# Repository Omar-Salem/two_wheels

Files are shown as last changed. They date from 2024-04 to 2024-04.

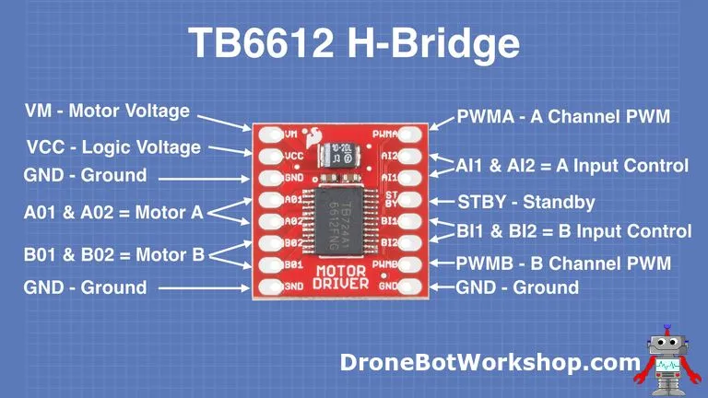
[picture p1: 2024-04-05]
two_wheels_core/firmware/docs/TB6612FNG-pinout.png

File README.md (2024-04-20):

### Validate URDF file

``` bash 
check_urdf two_wheels_core/urdf/robot_core.xacro
```

## Build and run simulation

```bash
cd ros2_ws/
rm -rf build/ install/ log/
colcon build && source install/setup.bash && ros2 launch two_wheels_core sim_two_wheels.launch.py
````

## Build and run real

[//]: # (### Log into on Pi)

[//]: # (```bash)

[//]: # (ssh omar.salem@192.168.1.35)

[//]: # (```)

### Prepare docker on Pi (_first time/on code change_)
```bash
HOST=omar.salem@192.168.1.35
scp prepare_docker.sh $HOST:/tmp/ && ssh -t $HOST "sudo -s bash /tmp/prepare_docker.sh"
```

### Run microros

```bash
ssh omar.salem@192.168.1.35
docker run --rm --privileged -it -v ~/Volumes:/home/usr/ humble
#contents of run_microros.sh
```

### Run robot

```bash
ssh omar.salem@192.168.1.35
docker exec -it $(docker container ls  | grep 'humble' | awk '{print $1}') bash
#contents of run_robot.sh
```

### Test
```bash
ssh omar.salem@192.168.1.35
docker exec -it $(docker container ls  | grep 'humble' | awk '{print $1}') bash
ros2 topic pub -r 10 /diff_drive_controller/cmd_vel_unstamped geometry_msgs/msg/Twist "
  linear:
    x: 0.5"

````

### Debug

- Is Esp32 LED on?
- Do Motors Have power ?
```bash

ls /dev/tty* | grep USB #sanity check to see if usb devices are reachable
ros2 topic list | grep motors #sanity check to see if /two_wheels/motors_* topics exist

source ~/microros_ws/install/local_setup.bash
ros2 topic echo /two_wheels/motors_state #sanity check to see if topics emit

ros2 topic pub -r 10 /two_wheels/motors_cmd two_wheels_interfaces/msg/MotorsOdom "m1:
  velocity: 1.5
m2:
  velocity: 1.50"
````

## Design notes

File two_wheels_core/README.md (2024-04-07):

### Validate URDF file

```check_urdf /PATH/TO/URDF```

### Build and run simulation

```bash
cd ros2_ws/
rm -rf build/ install/ log/
colcon build && source install/setup.bash && ros2 launch two_wheels_core sim_two_wheels.launch.py
````

### Log into on Pi
```bash
ssh omar.salem@192.168.1.35
```

### Prepare docker on Pi (first time/on repo change)
```bash
sudo rm -rf ~/Volumes
mkdir -p ~/Volumes/ros2_ws/src
cd ~/Volumes
mkdir microros_ws
cd $_
git clone -b humble https://github.com/micro-ROS/micro_ros_setup.git src/micro_ros_setup
cd ~/Volumes/ros2_ws/src
git clone https://github.com/Omar-Salem/two_wheels.git
git clone https://github.com/Slamtec/sllidar_ros2.git
pip install -U colcon-common-extensions
source sllidar_ros2/scripts/create_udev_rules.sh
mv two_wheels/* ~/Volumes/ros2_ws/src/
#mv two_wheels/Dockerfile ~/Volumes/ros2_ws/src/  # TODO needed?
rm -rf two_wheels
docker system prune --volumes --all -f
docker build -t humble .
```

### Build and run real

```bash
ls /dev/tty* | grep USB #sanity check to see if usb devices are reachable
docker run --rm --privileged -it -v ~/Volumes:/home/usr/ humble

ros2 topic list | grep motors #sanity check to see if topics exist

ros2 topic pub -r 10 /diff_drive_controller/cmd_vel_unstamped geometry_msgs/msg/Twist "
  linear:
    x: 1.0
    y: 0.0
    z: 0.0
  angular:
    x: 0.0
    y: 0.0
    z: 0.0"
````

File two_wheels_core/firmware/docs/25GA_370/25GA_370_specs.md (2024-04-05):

https://mikroelectron.com/Product/25GA-370-12V-400RPM-DC-Reducer-Gear-Motor-with-Encoder

| Power Source | Board | ESP32 | Motors | TB6612FNG |
|---|---|---|---|---|
| + | | | | VM |
| GND | GND | GND | M1 Black  - negative of encoder power supply(-)(3.3-5V) | GND |
| | + | 5V | M1 BLue - positive of encoder power supply(+)(3.3-5V) | STBY,VCC |
| | | | M1 Red  - positive power supply (+) | A0 |
| | | | M1 White  - negative power supply (-) | A1 |
| | | 16 | | PWMA |
| | | 4 | | AI1 |
| | | 0 | | AI2 |
| | | 23 | M1 Yellow | |
| | | 22 | M1 Green | |
| -------------- | ------- | ------- | --------------------------------------------------------- | ----------- |
| | GND | | M2 Black  - negative of encoder power supply(-)(3.3-5V) | |
| | + | | M2 BLue - positive of encoder power supply(+)(3.3-5V) | |
| | | | M2 White  - negative power supply  (-) | B0 |
| | | | M2 Red  - positive power supply (+) | B1 |
| | | 27 | | PWMB |
| | | 12 | | BI1 |
| | | 14 | | BI2 |
| | | 36 | M2 Yellow  - M2 | |
| | | 39 | M2 Green  - M2 | |

https://www.openimpulse.com/blog/products-page/25d-gearmotors/jga25-370-dc-gearmotor-77-rpm-6-v/

Specifications
Operating voltage: between 3 V and 9 V
Nominal voltage: 6 V
Free-run speed at 6 V: 77 RPM
Free-run current at 6 V: 80 mA
Stall current at 6V: 900 mA
Stall torque at 6V: 10 kg·cm
Gear ratio: 1:78
Reductor size: 23 mm
Weight: 88 g

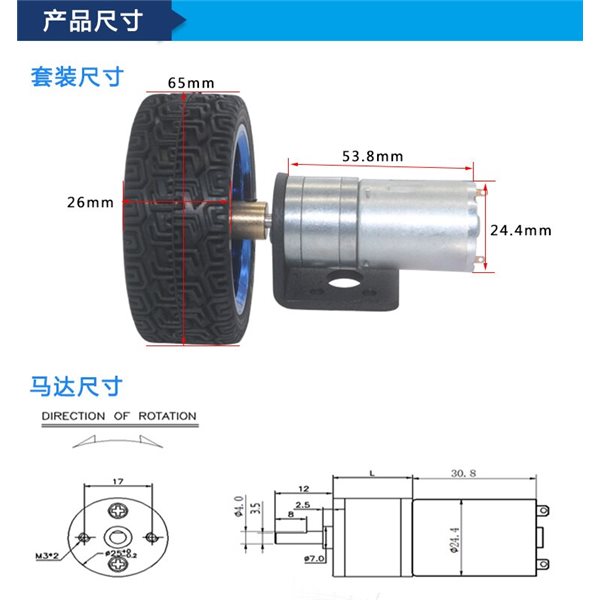
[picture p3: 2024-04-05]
two_wheels_core/firmware/docs/25GA_370/dimensions.jpg

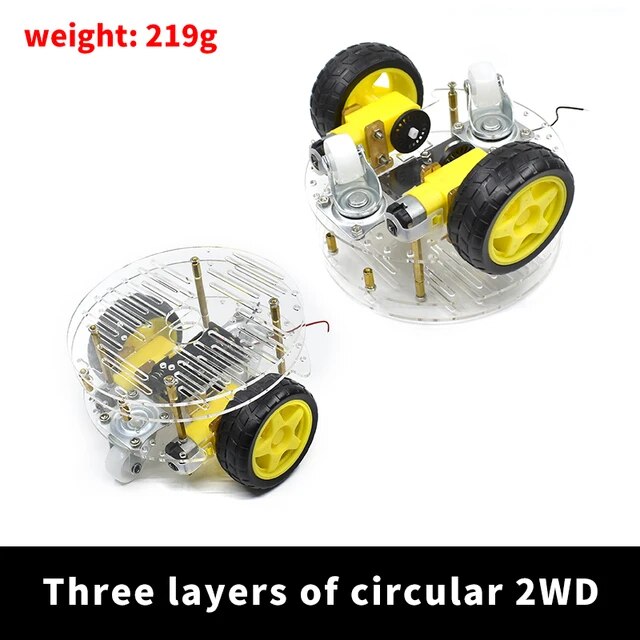
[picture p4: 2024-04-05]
two_wheels_core/firmware/docs/robot.png

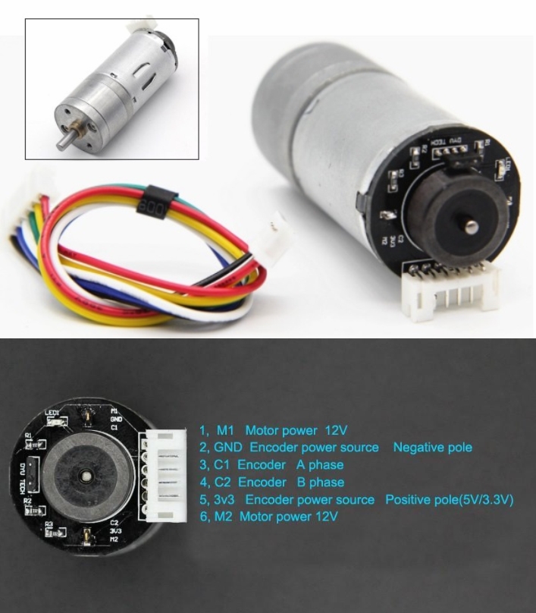
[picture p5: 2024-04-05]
two_wheels_core/firmware/docs/25GA_370/25GA-370 6V 620RPM DC REDUCER GEAR MOTOR WITH ENCODER.jpg

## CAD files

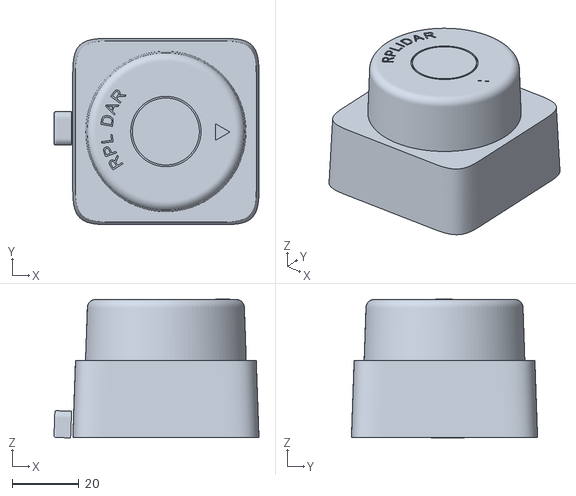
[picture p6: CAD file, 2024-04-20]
two_wheels_core/urdf/meshes/lidar_link.stl
61.2 x 55.6 x 41.5

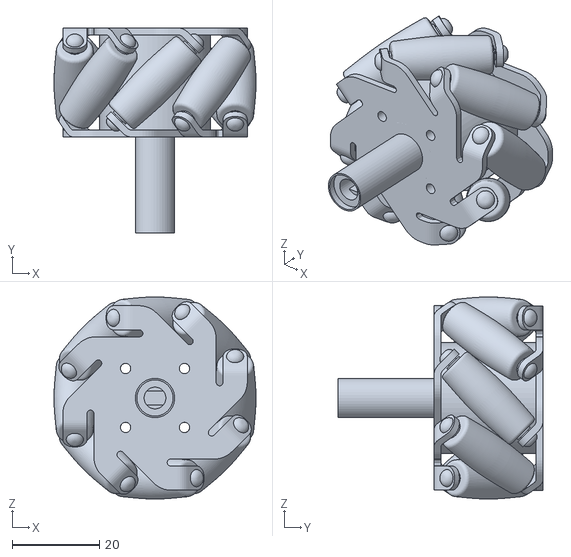
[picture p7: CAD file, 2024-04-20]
two_wheels_core/urdf/meshes/front_left_wheel.stl
46.3 x 47.0 x 46.3

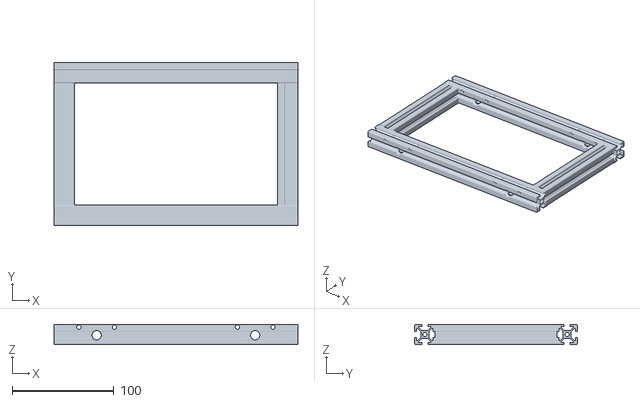
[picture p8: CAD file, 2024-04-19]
two_wheels_core/urdf/meshes/base_link.stl
240.0 x 160.0 x 20.0

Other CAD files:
two_wheels_core/urdf/meshes/rear_right_wheel.stl
two_wheels_core/urdf/meshes/front_right_wheel.stl
two_wheels_core/urdf/meshes/rear_left_wheel.stl

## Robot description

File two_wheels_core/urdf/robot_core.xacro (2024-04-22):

<?xml version="1.0"?>
<robot xmlns:xacro="http://www.ros.org/wiki/xacro">
    <xacro:include filename="$(find two_wheels_core)/urdf/materials.xacro"/>
    <link name="base_link">
        <inertial>
            <origin xyz="7.136447167432144e-05 3.453515765351803e-05 0.024408245184796683" rpy="0 0 0"/>
            <mass value="1.000593039456424"/>
            <inertia ixx="0.003708" iyy="0.007317" izz="0.010943" ixy="-0.0" iyz="-0.0" ixz="-0.0"/>
        </inertial>
        <visual>
            <origin xyz="0 0 0" rpy="0 0 0"/>
            <geometry>
                <mesh filename="file://$(find two_wheels_core)/urdf/meshes/base_link.stl" scale="0.001 0.001 0.001"/>
            </geometry>
            <material name="silver"/>
        </visual>
        <collision>
            <origin xyz="0 0 0" rpy="0 0 0"/>
            <geometry>
                <mesh filename="file://$(find two_wheels_core)/urdf/meshes/base_link.stl" scale="0.001 0.001 0.001"/>
            </geometry>
        </collision>
    </link>

    <link name="rear_right_wheel">
        <inertial>
            <origin xyz="1.625960121487413e-06 -0.03356595189466297 -1.9609319341917786e-09" rpy="0 0 0"/>
            <mass value="0.21820489062799583"/>
            <inertia ixx="3.8e-05" iyy="4.8e-05" izz="3.8e-05" ixy="0.0" iyz="0.0" ixz="0.0"/>
        </inertial>
        <visual>
            <origin xyz="0.077933 0.059968 -0.023743" rpy="0 0 0"/>
            <geometry>
                <mesh filename="file://$(find two_wheels_core)/urdf/meshes/rear_right_wheel.stl" scale="0.001 0.001 0.001"/>
            </geometry>
            <material name="black"/>
        </visual>
        <collision>
            <origin xyz="0.077933 0.059968 -0.023743" rpy="0 0 0"/>
            <geometry>
                <mesh filename="file://$(find two_wheels_core)/urdf/meshes/rear_right_wheel.stl" scale="0.001 0.001 0.001"/>
            </geometry>
        </collision>
    </link>

    <link name="front_right_wheel">
        <inertial>
            <origin xyz="1.3407781088436987e-06 -0.03356595189466117 -1.9609318023527944e-09" rpy="0 0 0"/>
            <mass value="0.2182048906279955"/>
            <inertia ixx="3.8e-05" iyy="4.8e-05" izz="3.8e-05" ixy="0.0" iyz="0.0" ixz="0.0"/>
        </inertial>
        <visual>
            <origin xyz="-0.077933 0.059968 -0.023743" rpy="0 0 0"/>
            <geometry>
                <mesh filename="file://$(find two_wheels_core)/urdf/meshes/front_right_wheel.stl" scale="0.001 0.001 0.001"/>
            </geometry>
            <material name="black"/>
        </visual>
        <collision>
            <origin xyz="-0.077933 0.059968 -0.023743" rpy="0 0 0"/>
            <geometry>
                <mesh filename="file://$(find two_wheels_core)/urdf/meshes/front_right_wheel.stl" scale="0.001 0.001 0.001"/>
            </geometry>
        </collision>
    </link>

    <link name="front_left_wheel">
        <inertial>
            <origin xyz="1.4899030495729715e-06 0.03356602362407317 3.1974513525767634e-07" rpy="0 0 0"/>
            <mass value="0.2182048906279955"/>
            <inertia ixx="3.8e-05" iyy="4.8e-05" izz="3.8e-05" ixy="-0.0" iyz="0.0" ixz="-0.0"/>
        </inertial>
        <visual>
            <origin xyz="-0.077931 -0.060032 -0.023742" rpy="0 0 0"/>
            <geometry>
                <mesh filename="file://$(find two_wheels_core)/urdf/meshes/front_left_wheel.stl" scale="0.001 0.001 0.001"/>
            </geometry>
            <material name="black"/>
        </visual>
        <collision>
            <origin xyz="-0.077931 -0.060032 -0.023742" rpy="0 0 0"/>
            <geometry>
                <mesh filename="file://$(find two_wheels_core)/urdf/meshes/front_left_wheel.stl" scale="0.001 0.001 0.001"/>
            </geometry>
        </collision>
    </link>

    <link name="rear_left_wheel">
        <inertial>
            <origin xyz="-1.489903047255381e-06 0.033566023624073626 8.554326641832533e-08" rpy="0 0 0"/>
            <mass value="0.2182048906279955"/>
            <inertia ixx="3.8e-05" iyy="4.8e-05" izz="3.8e-05" ixy="0.0" iyz="-0.0" ixz="-0.0"/>
        </inertial>
        <visual>
            <origin xyz="0.077931 -0.060032 -0.023742" rpy="0 0 0"/>
            <geometry>
                <mesh filename="file://$(find two_wheels_core)/urdf/meshes/rear_left_wheel.stl" scale="0.001 0.001 0.001"/>
            </geometry>
            <material name="black"/>
        </visual>
        <collision>
            <origin xyz="0.077931 -0.060032 -0.023742" rpy="0 0 0"/>
            <geometry>
                <mesh filename="file://$(find two_wheels_core)/urdf/meshes/rear_left_wheel.stl" scale="0.001 0.001 0.001"/>
            </geometry>
        </collision>
    </link>

    <joint name="rear_right_wheel_joint" type="continuous">
        <origin xyz="-0.077933 -0.059968 0.023743" rpy="0 0 0"/>
        <parent link="base_link"/>
        <child link="rear_right_wheel"/>
        <axis xyz="0.0 1.0 0.0"/>
    </joint>

    <joint name="front_right_wheel_joint" type="continuous">
        <origin xyz="0.077933 -0.059968 0.023743" rpy="0 0 0"/>
        <parent link="base_link"/>
        <child link="front_right_wheel"/>
        <axis xyz="0.0 1.0 0.0"/>
    </joint>

    <joint name="front_left_wheel_joint" type="continuous">
        <origin xyz="0.077931 0.060032 0.023742" rpy="0 0 0"/>
        <parent link="base_link"/>
        <child link="front_left_wheel"/>
        <axis xyz="0.0 1.0 0.0"/>
    </joint>

    <joint name="rear_left_wheel_joint" type="continuous">
        <origin xyz="-0.077931 0.060032 0.023742" rpy="0 0 0"/>
        <parent link="base_link"/>
        <child link="rear_left_wheel"/>
        <axis xyz="0.0 1.0 0.0"/>
    </joint>

    <link name="lidar_link">
        <inertial>
            <origin xyz="-0.00011530732368342234 3.558559248059221e-06 0.017945212221916012" rpy="0 0 0"/>
            <mass value="0.7886321015037847"/>
            <inertia ixx="0.000269" iyy="0.000272" izz="0.000333" ixy="0.0" iyz="0.0" ixz="-1e-06"/>
        </inertial>
        <visual>
            <origin xyz="-0.11007 -3.2e-05 -0.028463" rpy="0 0 0"/>
            <geometry>
                <mesh filename="file://$(find two_wheels_core)/urdf/meshes/lidar_link.stl" scale="0.001 0.001 0.001"/>
            </geometry>
            <material name="black"/>
        </visual>
        <collision>
            <origin xyz="-0.11007 -3.2e-05 -0.028463" rpy="0 0 0"/>
            <geometry>
                <mesh filename="file://$(find two_wheels_core)/urdf/meshes/lidar_link.stl" scale="0.001 0.001 0.001"/>
            </geometry>
        </collision>
    </link>

    <joint name="lidar_link_joint" type="fixed">
        <origin xyz="0.11007 3.2e-05 0.028463" rpy="0 0 0"/>
        <parent link="base_link"/>
        <child link="lidar_link"/>
    </joint>

    <link name="base_footprint"/>

    <joint name="base_footprint_joint" type="fixed">
        <parent link="base_link"/>
        <child link="base_footprint"/>
        <origin xyz="0 0 0" rpy="0 0 0"/>
    </joint>

</robot>

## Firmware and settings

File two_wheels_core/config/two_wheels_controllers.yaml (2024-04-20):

controller_manager:
  ros__parameters:
    update_rate: 10  # Hz
    use_sim_time: false

    joint_state_broadcaster:
      type: joint_state_broadcaster/JointStateBroadcaster

    diff_drive_controller:
      type: diff_drive_controller/DiffDriveController

diff_drive_controller:
  ros__parameters:
    wheels_per_side: 2
    left_wheel_names: [ "front_left_wheel_joint" ,"rear_left_wheel_joint" ]
    right_wheel_names: [ "front_right_wheel_joint","rear_right_wheel_joint" ]

    wheel_separation: 0.164
    wheel_radius: 0.024

    use_stamped_vel: false
    #    wheel_separation_multiplier: 1.0
    #    left_wheel_radius_multiplier: 1.0
    #    right_wheel_radius_multiplier: 1.0
    #
    #    publish_rate: 50.0
    #    odom_frame_id: odom
    #    base_frame_id: base_link
    #    pose_covariance_diagonal : [0.001, 0.001, 0.001, 0.001, 0.001, 0.01]
    #    twist_covariance_diagonal: [0.001, 0.001, 0.001, 0.001, 0.001, 0.01]
    #
    open_loop: false
    position_feedback: true
#    enable_odom_tf: true
#
#    cmd_vel_timeout: 0.5
#    #publish_limited_velocity: true
#    #velocity_rolling_window_size: 10
#
#    # Velocity and acceleration limits
#    # Whenever a min_* is unspecified, default to -max_*
#    linear.x.has_velocity_limits: true
#    linear.x.has_acceleration_limits: true
#    linear.x.has_jerk_limits: false
#    linear.x.max_velocity: 1.0
#    linear.x.min_velocity: -1.0
#    linear.x.max_acceleration: 1.0
#    linear.x.max_jerk: 0.0
#    linear.x.min_jerk: 0.0
#
#    angular.z.has_velocity_limits: true
#    angular.z.has_acceleration_limits: true
#    angular.z.has_jerk_limits: false
#    angular.z.max_velocity: 1.0
#    angular.z.min_velocity: -1.0
#    angular.z.max_acceleration: 1.0
#    angular.z.min_acceleration: -1.0
#    angular.z.max_jerk: 0.0
#    angular.z.min_jerk: 0.0

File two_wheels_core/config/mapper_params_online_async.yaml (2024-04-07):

slam_toolbox:
  ros__parameters:

    # Plugin params
    solver_plugin: solver_plugins::CeresSolver
    ceres_linear_solver: SPARSE_NORMAL_CHOLESKY
    ceres_preconditioner: SCHUR_JACOBI
    ceres_trust_strategy: LEVENBERG_MARQUARDT
    ceres_dogleg_type: TRADITIONAL_DOGLEG
    ceres_loss_function: None

    # ROS Parameters
    odom_frame: odom
    map_frame: map
    base_frame: base_footprint
    scan_topic: /scan
    use_map_saver: true
    mode: localization #TODO pass in runtime
    #    mode: mapping #localization #TODO pass in runtime

    # if you'd like to immediately start continuing a map at a given pose
    # or at the dock, but they are mutually exclusive, if pose is given
    # will use pose
    map_file_name: /home/omar/ros2_ws/src/two_wheels_core/maps/apt #TODO pass in runtime
    # map_start_pose: [0.0, 0.0, 0.0]
    map_start_at_dock: true

    debug_logging: false
    throttle_scans: 1
    transform_publish_period: 0.02 #if 0 never publishes odometry
    map_update_interval: 5.0
    resolution: 0.05
    max_laser_range: 20.0 #for rastering images
    minimum_time_interval: 0.5
    transform_timeout: 0.2
    tf_buffer_duration: 30.
    stack_size_to_use: 40000000 #// program needs a larger stack size to serialize large maps
    enable_interactive_mode: true

    # General Parameters
    use_scan_matching: true
    use_scan_barycenter: true
    minimum_travel_distance: 0.5
    minimum_travel_heading: 0.5
    scan_buffer_size: 10
    scan_buffer_maximum_scan_distance: 10.0
    link_match_minimum_response_fine: 0.1
    link_scan_maximum_distance: 1.5
    loop_search_maximum_distance: 3.0
    do_loop_closing: true
    loop_match_minimum_chain_size: 10
    loop_match_maximum_variance_coarse: 3.0
    loop_match_minimum_response_coarse: 0.35
    loop_match_minimum_response_fine: 0.45

    # Correlation Parameters - Correlation Parameters
    correlation_search_space_dimension: 0.5
    correlation_search_space_resolution: 0.01
    correlation_search_space_smear_deviation: 0.1

    # Correlation Parameters - Loop Closure Parameters
    loop_search_space_dimension: 8.0
    loop_search_space_resolution: 0.05
    loop_search_space_smear_deviation: 0.03

    # Scan Matcher Parameters
    distance_variance_penalty: 0.5
    angle_variance_penalty: 1.0

    fine_search_angle_offset: 0.00349
    coarse_search_angle_offset: 0.349
    coarse_angle_resolution: 0.0349
    minimum_angle_penalty: 0.9
    minimum_distance_penalty: 0.5
    use_response_expansion: true

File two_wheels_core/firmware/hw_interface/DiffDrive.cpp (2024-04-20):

// Copyright (c) 2024, omar.salem
// All rights reserved.
//
// Proprietary License
//
// Unauthorized copying of this file, via any medium is strictly prohibited.
// The file is considered confidential.

#include <limits>
#include <vector>

#include "DiffDrive.h"
#include "hardware_interface/types/hardware_interface_type_values.hpp"
#include "rclcpp/rclcpp.hpp"
#include "pluginlib/class_list_macros.hpp"


namespace hw_interface {
    DiffDrive::DiffDrive() : node_(std::make_shared<rclcpp::Node>("two_wheels_motors_hw_interface_node")) {
        odomSubscription = node_->create_subscription<two_wheels_interfaces::msg::MotorsOdom>(
                "two_wheels/motors_state", 10,
                [this](const two_wheels_interfaces::msg::MotorsOdom::SharedPtr motorsOdom) {
                    this->readOdom(motorsOdom);
                });
        velocityPublisher = node_->create_publisher<two_wheels_interfaces::msg::MotorsOdom>("two_wheels/motors_cmd",
                                                                                            10);
    }

    CallbackReturn DiffDrive::on_init(
            const HardwareInfo &info) {
        RCLCPP_INFO(get_logger("DiffDrive"), "on_init ...please wait...");

        if (SystemInterface::on_init(info) != CallbackReturn::SUCCESS) {
            return CallbackReturn::ERROR;
        }
        frontLeftWheel = make_unique<Wheel>("front_left_wheel_joint");
        frontRightWheel = make_unique<Wheel>("front_right_wheel_joint");
        rearLeftWheel = make_unique<Wheel>("rear_left_wheel_joint");
        rearRightWheel = make_unique<Wheel>("rear_right_wheel_joint");
        return CallbackReturn::SUCCESS;
    }

    CallbackReturn DiffDrive::on_configure(
            const State & /*previous_state*/) {
        RCLCPP_INFO(get_logger("DiffDrive"), "on_configure ...please wait...");
        return CallbackReturn::SUCCESS;
    }

    vector <StateInterface> DiffDrive::export_state_interfaces() {
        RCLCPP_INFO(get_logger("DiffDrive"), "export_state_interfaces ...please wait...");
        vector <StateInterface> state_interfaces;

//        frontLeftWheel
        state_interfaces.emplace_back(
                frontLeftWheel->name, HW_IF_POSITION, &frontLeftWheel->position_state);

        state_interfaces.emplace_back(
                frontLeftWheel->name, HW_IF_VELOCITY, &frontLeftWheel->velocity_state);

//        frontRightWheel
        state_interfaces.emplace_back(
                frontRightWheel->name, HW_IF_POSITION, &frontRightWheel->position_state);

        state_interfaces.emplace_back(
                frontRightWheel->name, HW_IF_VELOCITY, &frontRightWheel->velocity_state);

//        rearLeftWheel
        state_interfaces.emplace_back(
                rearLeftWheel->name, HW_IF_POSITION, &rearLeftWheel->position_state);

        state_interfaces.emplace_back(
                rearLeftWheel->name, HW_IF_VELOCITY, &rearLeftWheel->velocity_state);

//        rearRightWheel
        state_interfaces.emplace_back(
                rearRightWheel->name, HW_IF_POSITION, &rearRightWheel->position_state);

        state_interfaces.emplace_back(
                rearRightWheel->name, HW_IF_VELOCITY, &rearRightWheel->velocity_state);

        return state_interfaces;
    }

    vector <CommandInterface> DiffDrive::export_command_interfaces() {
        RCLCPP_INFO(get_logger("DiffDrive"), "export_command_interfaces ...please wait...");
        vector <CommandInterface> command_interfaces;
        command_interfaces.emplace_back(
                frontLeftWheel->name, HW_IF_VELOCITY, &frontLeftWheel->velocity_command);
        command_interfaces.emplace_back(
                frontRightWheel->name, HW_IF_VELOCITY, &frontRightWheel->velocity_command);
        command_interfaces.emplace_back(
                rearLeftWheel->name, HW_IF_VELOCITY, &rearLeftWheel->velocity_command);
        command_interfaces.emplace_back(
                rearRightWheel->name, HW_IF_VELOCITY, &rearRightWheel->velocity_command);

        return command_interfaces;
    }

    CallbackReturn DiffDrive::on_activate(
            const State & /*previous_state*/) {
        RCLCPP_INFO(get_logger("DiffDrive"), "on_activate ...please wait...");
        return CallbackReturn::SUCCESS;
    }

    CallbackReturn DiffDrive::on_deactivate(
            const State & /*previous_state*/) {
        RCLCPP_INFO(get_logger("DiffDrive"), "on_deactivate ...please wait...");
        setMotorsVelocity(0, 0, 0, 0);
        return CallbackReturn::SUCCESS;
    }

    return_type DiffDrive::read(
            const Time & /*time*/, const Duration & /*period*/) {
        rclcpp::spin_some(node_);
        return return_type::OK;
    }

    return_type DiffDrive::write(
            const Time & /*time*/, const Duration & /*period*/) {
        setMotorsVelocity(frontLeftWheel->velocity_command,
                          frontRightWheel->velocity_command,
                          rearLeftWheel->velocity_command,
                          rearRightWheel->velocity_command);
        return return_type::OK;
    }

    void DiffDrive::setMotorsVelocity(double frontLeft,
                                      double frontRight,
                                      double rearLeft,
                                      double rearRight) {
        auto cmd_msg = std::make_shared<two_wheels_interfaces::msg::MotorsOdom>();
        cmd_msg->front_left.velocity = frontLeft;
        cmd_msg->front_right.velocity = frontRight;
        cmd_msg->rear_left.velocity = rearLeft;
        cmd_msg->rear_right.velocity = rearRight;
        velocityPublisher->publish(*cmd_msg);
    }

    void DiffDrive::readOdom(const two_wheels_interfaces::msg::MotorsOdom::SharedPtr motorsOdom) {
        frontLeftWheel->position_state = motorsOdom->front_left.position;
        frontLeftWheel->velocity_state = motorsOdom->front_left.velocity;

        frontRightWheel->position_state = motorsOdom->front_right.position;
        frontRightWheel->velocity_state = motorsOdom->front_right.velocity;

        rearLeftWheel->position_state = motorsOdom->rear_left.position;
        rearLeftWheel->velocity_state = motorsOdom->rear_left.velocity;

        rearRightWheel->position_state = motorsOdom->rear_right.position;
        rearRightWheel->velocity_state = motorsOdom->rear_right.velocity;
    }

}


PLUGINLIB_EXPORT_CLASS(hw_interface::DiffDrive, SystemInterface
)

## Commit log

2024-04-07 changed package name from two_wheels to two_wheels_core
    [gazebo_control.xacro]
2024-04-07 fixed use_sim_time in real launch, add lidar launch file
2024-04-07 fixing urdf and launch files
    [robot.urdf.xacro, robot_core.xacro]
2024-04-07 fixed laser not showing in rviz by setting the rplidar launch file frame_id arg
2024-04-07 fixed getting stepper position in radians
2024-04-07 fixed odom! subscriber call back needed to be split into own function + calling rclcpp::spin_some(node_); in read method
    [DiffDrive.cpp]
2024-04-09 fixed wheel odom going crazy by not resetting wheel position
2024-04-09 made odom the fixed frame
2024-04-11 fixed jittering by changing priority of stepper move task from 1 to 0
    [esp32.ino]
2024-04-13 added led to check if esp32 is active
2024-04-13 replaced range with laser_scan
2024-04-14 removed dead man's switch
2024-04-16 bump_go FSM
    [robot.urdf.xacro, robot_core.xacro, sonar.xacro]
2024-04-19 updated wheels' and joint's names
    [joints.macro.xacro, materials.xacro, robot_core.xacro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]
2024-04-19 disabled imu & lidar
    [base_link.stl, front_left_wheel.stl, front_right_wheel.stl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]
2024-04-19 removed caster wheel
    [robot_core.xacro]
2024-04-19 changed wheel_radius to 0.024
    [robot_core.xacro]
2024-04-20 renamed robot.urdf.xacro to robot.xacro
    [materials.xacro, robot.xacro]
2024-04-20 finally worked using https://github.com/dheena2k2/fusion2urdf-ros2
    [base_link.stl, front_left_wheel.stl, front_right_wheel.stl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]
2024-04-20 4 wheel drive from fusion 360
    [base_link.stl, common_inertias.xacro, front_left_wheel.stl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]
2024-04-20 added rear wheels to ros2control yaml
    [two_wheels_controllers.yaml]
2024-04-20 added wheels_per_side and updated wheel_separation in ros2control yaml
    [two_wheels_controllers.yaml]
2024-04-20 4 wheel drive working!
    [robot_core.xacro]
2024-04-20 fixed lidar_link.stl path
    [robot_core.xacro]
2024-04-20 4 wheels wiring
2024-04-20 fixed gazebo color
    [gazebo.xacro]
2024-04-21 fixed pin order
2024-04-22 updated wheels' names
    [front_left_wheel.stl, front_right_wheel.stl, rear_left_wheel.stl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]
2024-04-23 removed led
